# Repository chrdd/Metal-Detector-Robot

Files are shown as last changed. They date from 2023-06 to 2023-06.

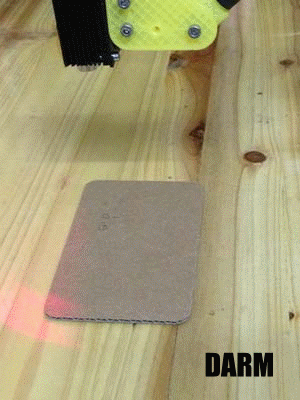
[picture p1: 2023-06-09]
Resources/1204552_3d_print_desktop_robot_arm_DARM_/images/.gif

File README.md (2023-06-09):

# Metal-Detector-Robot
## Introduction
This personal project is aimed at enhancing my knowledge of robotics and Arduinos.

The project initially involved creating a prototype of a metal detector robot with increased degrees of freedom, enabling it to reach greater distances. 


Considering the rising costs of metalworking, I also wanted to develop a cost-effective solution, which led me to research 3D printed arms. I aimed to combine elements from two existing designs:

With metal working being more and more expensive, I also wanted to make something that could be cheap to produce, so I began to do reasearch on 3D printed arms.

I wanted to find a mix between these 2 designs:




Additionally, I aimed to automate the robot as the previous designs relied on manual control through a remote.

## Achitecture
The robot consists of a 4WD project kit car comprising an L298N motor driver and four DC motors, an Arduino Uno, a Raspberry Pi 3A, two NEMA OKY7414 stepper motors, an MG996 servo, a metal detector kit, two stepper drivers, a CNC V3 hat for the Arduino, batteries, and wiring. To complete the arm assembly, I 3D printed a robot arm from Thingiverse ([RobotArm by ftobler - Thingiverse](https://www.thingiverse.com/thing:1718984)), originally intended for an Arduino Mega. The arm required bearings and screws for proper functionality.

### Electrical connections

## Software
The entire project revolves around GRBL, a lightweight G Code interpreter developed in C. This setup allows the Raspberry Pi to calculate the required movements and the Arduino to execute them through the CNC hat, enabling more complex control of the arm.

While GRBL officially supports only stepper motors, there is a modified version called [**grbl-servo**](https://github.com/cprezzi/grbl-servo) that also supports servo control.

G-Code is transmitted from the Raspberry Pi to the Arduino using a serial connection. Additionally, the metal detector sends a high pulse to the Raspberry Pi through pin 36. Furthermore, alongside controlling the arm, the Raspberry Pi manages the DC motors, enabling the car to move.

## Final assembly



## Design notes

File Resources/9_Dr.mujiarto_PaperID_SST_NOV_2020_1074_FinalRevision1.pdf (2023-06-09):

See discussions, stats, and author profiles for this publication at: https://www.researchgate.net/publication/355840656
Design of Arduino-Based Metal Detector Robot (https://www.researchgate.net/publication/355840656_Design_of_Arduino-Based_Metal_Detector_Robot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)

Article in Solid State Technology · November 2021

CITATION
1

READS
8,339

### 3 authors, including:

Some of the authors of this publication are also working on these related projects:

Modelling using artificial intelligence, View project (https://www.researchgate.net/project/Modelling-using-artificial-intelligence?el=1_x_9&_esc=publicationCoverPdf)

UMTAS GRANT View project (https://www.researchgate.net/project/UMTAS-GRANT?el=1_x_9&_esc=publicationCoverPdf)

Mujiarto Bin Parsusah (https://www.researchgate.net/profile/Mujiarto-Bin-Parsusah-2?el=1_x_5&_esc=publicationCoverPdf)
Universitas Muhammadiyah Tasikmalaya

### 48 PUBLICATIONS 156 CITATIONS

SEE PROFILE (https://www.researchgate.net/profile/Mujiarto-Bin-Parsusah-2?el=1_x_7&_esc=publicationCoverPdf)

Aceng Sambas (https://www.researchgate.net/profile/Aceng-Sambas?el=1_x_5&_esc=publicationCoverPdf)
Universitas Muhammadiyah Tasikmalaya

162 PUBLICATIONS 1,610 CITATIONS

SEE PROFILE (https://www.researchgate.net/profile/Aceng-Sambas?el=1_x_7&_esc=publicationCoverPdf)

All content following this page was uploaded by Mujiarto Bin Parsusah (https://www.researchgate.net/profile/Mujiarto-Bin-Parsusah-2?el=1_x_10&_esc=publicationCoverPdf) on 21 July 2022.

The user has requested enhancement of the downloaded file.

Solid State Technology
Volume: 63 Issue: 6
Publication Year: 2020

12401

Archives Available @ www.solidstatetechnology.us

# Design of Arduino-Based Metal Detector Robot

Mujiarto¹

, Aceng Sambas¹

, Irpan Haerudin ¹
1Department of Mechanical Engineering, Universitas Muhammadiyah Tasikmalaya, Indonesia

Corresponding Email: mujiarto@umtas.ac.id

Abstract- Metal Detector Robot is an instrument controlled by an Android-based smartphone that detects the presence of metal, especially landmines, on a designated location. The usage of landmines causing injury and fatality makes detectors important. The old method of detecting landmines such as direct sweeping is very risky for stepping the landmine unintentionally. In this research, the robot system is equipped with a metal detector useful to detect the metal presence based on coil induction when it's approaching the metal. LCD works as an interface showing frequencies of detected metals. The robot movement is controlled by DC's current motor programmed using Arduino UNO. When the robot detects the metal presence, the buzzer sound will be triggered, and the LCD will show the detected metal frequency. The testing result shows that an Android-based smartphone can control the robot up to 15 meters radius. The detection radius is effective up to 88 millimeters from the detector head.

Keywords- arduino uno, metal detector, design, robot

I. INTRODUCTION

We know a variety of materials including metal and non-metal materials. Non-metal materials that we know include wood, plastic, and other materials that are often used in everyday life. In general, metals are divided into ferrous metals and non-ferrous metals [1]. In everyday life, metal materials are usually used to conduct electricity, cooking utensils, jewelry, even for military purposes, one of which is the material for defense equipment such as mines. What we know in the military world, mines are usually planted below the surface of the ground, so that if they are pressed heavily, a mass trampled object will explode. Mines contain explosives that have certain physical and chemical properties [2], [3].

The existence of mines buried in the ground is difficult to know without the aid of tools. One of the tools used to detect the presence of mines is a metal detector [4]. Metal detectors contain a coil of wire known as a transmitter coil. When electricity flows through the coil, a magnetic field is created around the coil. When metal detectors are moved above the ground, the magnetic field will also move. When held close to a metal object, the magnetic field will affect the atoms inside the metal, even changing the way electrons move. The weakness of this metal detector is the high risk of victimization to users because its use still relies on direct human intervention.

Ease of doing a job is now a human need in carrying out its activities so that humans develop a breakthrough in utilizing technology. Utilization of technology to save time and costs. One solution to meet these needs is to use robotics technology that will help even replace some aspects of human work [5].

The use of robots as a tool, of course, is made as closely as possible with what humans do. Some robots are designed to have arms [4], robots that can follow certain colors [5] - [7], robots that can deliver food [8], robots that can guide parking [9], and of course those that are currently developing in connection with the outbreak. Covid-19 is a robot that can shop for daily necessities without the owner having to come to a supermarket or shop [10].

Smartphones communicate with the robot using a radio network (wireless) with the protocol Bluetooth. The data is sent by a cellphone via Bluetooth and received by the robot via adapter Bluetooth. The received data is modulated into serial data with ASCII format. The ASCII code is verified by the program to determine which commands to run. Metal detectors work based on the induction of metal objects in the

12402

enamel coil. The electric induction caused by the coil will change between the presence of metal and no metal. Based on these changes, the metal presence or not can be detected [7].

Metal detection robots are tools to detect the presence of metal or materials containing metal, this robot will notify the presence of metal around the robot by using light or sound [8], [9].

Research on metal detection robots has been carried out by several researchers to produce a metal detection robot design as desired [11] - [13]. Metal detection robot studies were developed based on a microcontroller, to make programming easier. Among them is a metal detection robot based on a microcontroller [11]. Several recent studies in robot design are based on Arduino [9], [14], [15], or some research based on Android [16]. The results of his research describe the application of using an inductive proximity sensor in a metal detector robot based on a 328 microcontroller. The way this robot works is controlled by a wireless remote radio frequency of 315 Mhz, previously a metal detector robot has installed a receiver with a signal that comes out of the wireless remote [12]. The previous metal detector robot was also entitled metal detector for the PLC-based food industry in 2011 [13]. Currently, PLC-based control is still widely used in industries whose equipment uses large power equipment, including in the food industry. The addition of a metal sensor will make it easier to detect food if it is accidentally mixed into food [17].

The purpose of this research is to design an android-based metal detection robot, which can be controlled by a smartphone connected to Bluetooth, with the reliability of being able to detect both ground and underground metals.

II. METHODS

A. Schematic of metal detection robot

This process describes the robot scheme to be built. This scheme is made to simplify the design process because the grooves or cable connections have been validated using the proteus software.

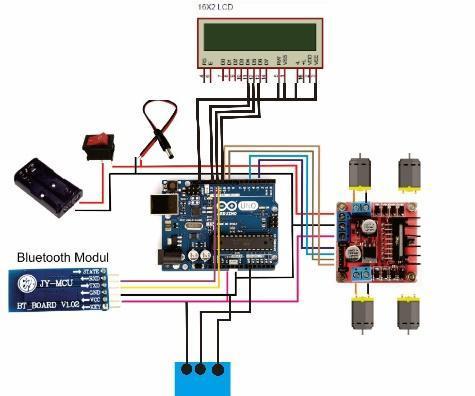
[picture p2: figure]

Figure 1. Scheme of metal detection robot

B. Robot Design
1) Frame

The robot is designed using 2 frames, both of which are made of acrylic material with dimensions of 250 mm x 140mm x 3mm, as shown in Figure 2.

12403

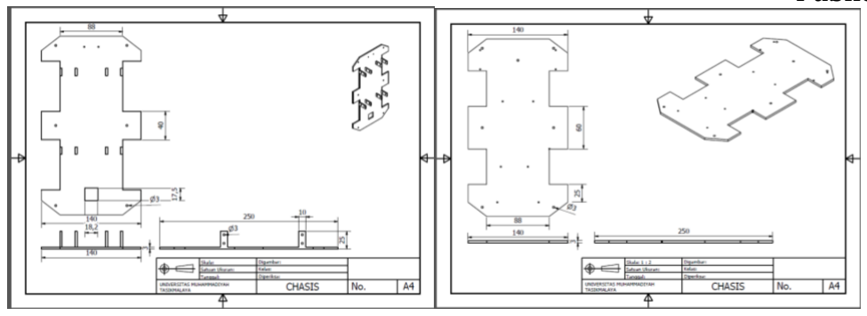
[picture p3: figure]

Figure 2. Frame

2) Gearbox (DC motor)

The drive used for this robot is to use a DC motor [14]. The use of a gearbox is needed to make efficient space on the chassis and change the shaft position of the DC motor because by using a gearbox, a dc motor that should be placed horizontally to distribute its rotation to the wheels can be positioned vertically with a fixed axle.

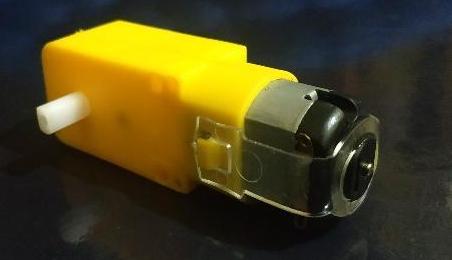
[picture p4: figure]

Figure 3. Gearbox (DC motor)

3) Metal sensor

This component is the most important part in the design of a metal sensor robot, with this component where the detected metal can be detected. For this study, researchers used metal sensors with the following specifications [7]. (a) Detection distance: 0-8mm; (b) Object of detection: Metal (Iron, Aluminum etc.); (c) Working voltage: 10-30V DC; (d)current Output: 300mA; (e) There are indicators: Yes (Red); (f) Working temperature: -25 to +70 C; (g) Size: 18x18x36 mm; (h) Cable length: 1.5m; (i) 34mm x 18.2mm x 17.5mm.

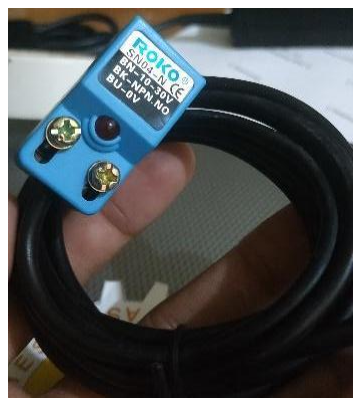
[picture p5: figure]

Figure 4. Metal sensor

4) Buzzer

This component is a component that converts electricity into sound. The buzzer will output the metal sensor robot. This tool will notify by emitting a sound when the metal sensor detects the presence of metal.

12404

Figure 5. Buzzer

5) Battery

This component is the power supply in metal detection robots. The battery used is a battery with a current of 9V, this battery is considered sufficient to supply all the electrical needs of the metal sensor robot, from starting to turn on 4 DC motors, motor drivers, Arduino, metal sensors, buzzer, and LCD dot matrix.

Figure 6. Battery

6) Arduino

Arduino is a board microcontroller, this tool will fully control the robot system from input and output according to what is ordered or programmed on the computer.

7) Motor driver

The motor driver is used to control the direction of rotation and speed of the DC motor [18] - [20], which is the main driving force of the robot. This motor driver will be controlled using a microcontroller by digital input data [7].

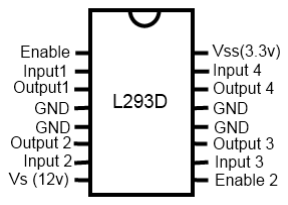
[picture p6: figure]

Figure 7. L239D pin configuration

8) LCD dot matrix

Character numbers, letters, and symbol characters can be displayed on this device, with small current consumption.

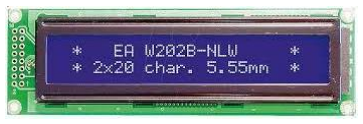
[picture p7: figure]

Figure 8. LCD Dot Matrix

12405

C. Software Design

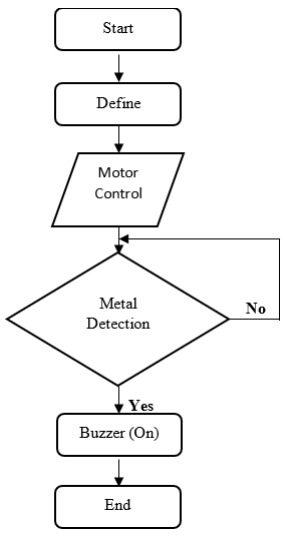
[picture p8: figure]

Figure 9. Flowchart of software design

D. Testing Stages of detector metal with metal variations and distances

Metal detector testing plans are shown in Table 1.

TABLE 1. Testing of metal detector

Metal Type | Distance (cm) | Buzzer
On | Off
Aluminium | 0,5
| 1
| 1,5
Iron | 0,5
| 1
| 1,5
Copper | 0,5
| 1
| 1,5
E. Robot reliability testing

In This testing phase we will measure the strength of the robot in climbing a slope of 30⁰ .

12406

TABLE 2. Robot reliability testing on an incline

Number | PWM | Result | Information
1 | 255
2 | 240
3 | 200
4 | 180
5 | 160

III. RESULTS AND DISCUSSION

A. Results of the Tool Design
1) Software

In the form of programs, the Arduino software program was used as the controller of all components of the robotic device. Arduino UNO is programmed using Arduino software as shown in Figure 10.

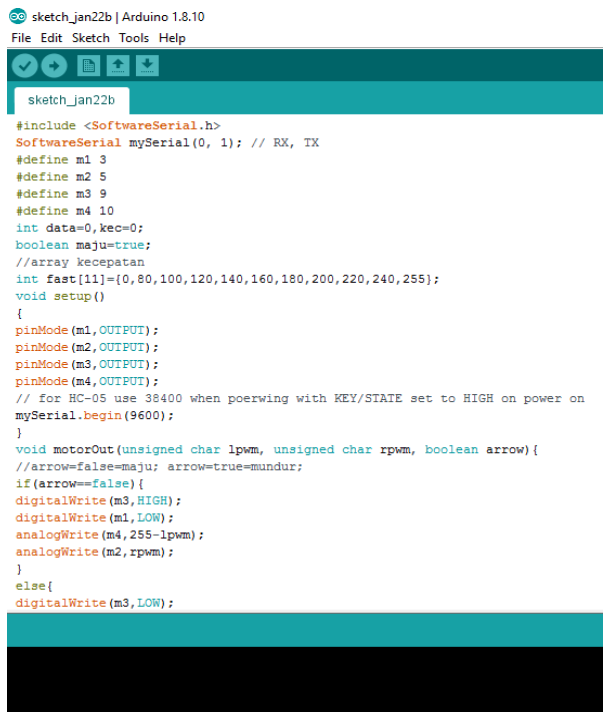
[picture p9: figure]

Figure 10. Program listing

B. Hardware
1) Design Frame

The mainframe of the robot is acrylic. The choice of acrylic material as the chassis is because it is strong, cheap, and easy to form with a size of 140 mm x 250 mm x 3 mm. The robot frame is divided into 2 parts, namely the lower part of the frame which is the support for 4 DC motors, metal sensors, a battery, and support for the upper frame. The upper part is a holder for Arduino, motor driver, buzzer, LCD, which can be seen in Figure 11.

12407

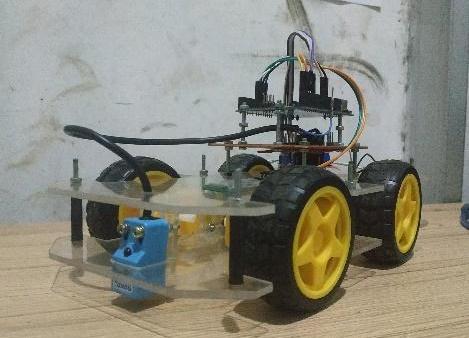
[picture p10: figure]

Figure 11. Results of design

2) The DC circuit

Robot use 4 dc motors as the main drive, this DC motor circuit (Figure 20) is connected to the L298N motor driver which functions to determine the direction of rotation of a dc motor.

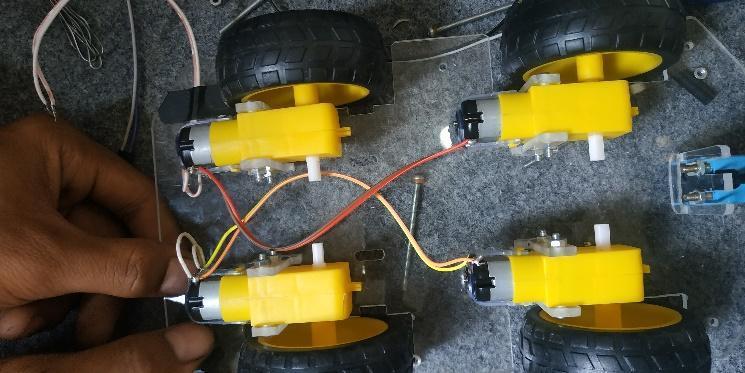
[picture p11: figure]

Figure 12. DC Motor Circuit

3) Robot control using smartphone android

The robot control circuit Bluetooth using smartphone android consists of a smartphone module Bluetooth, circuit Arduino UNO, motor driver L298N, and a DC motor. For more details, see Figure 13.

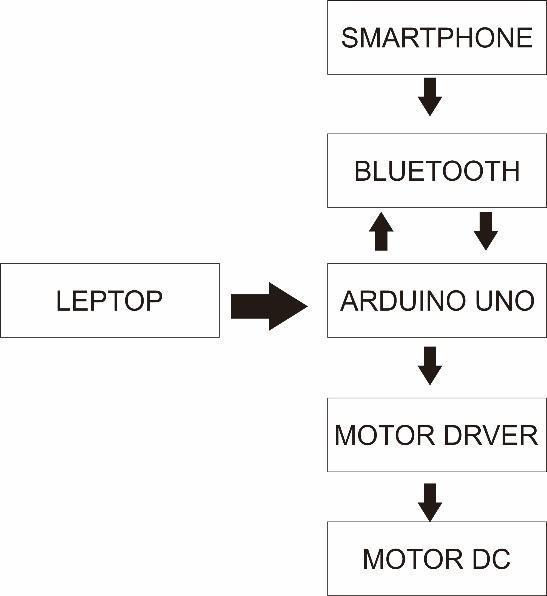
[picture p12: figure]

Figure 13. Robot control circuit

12408

To get a robot control circuit Bluetooth with a smartphone, there is a need for a connection between the module Bluetooth and Arduino using cable a male-female jumper. What must be connected can be seen in Figure 14.

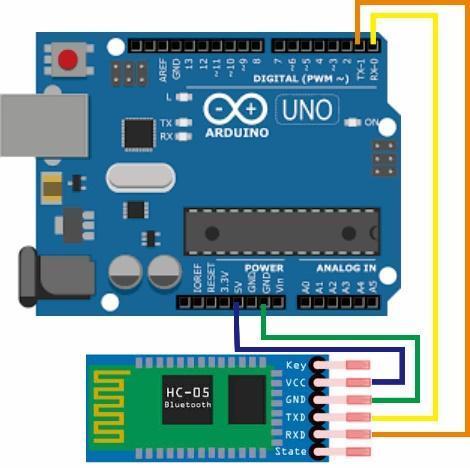
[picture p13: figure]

Figure 14. Bluetooth wiring on Arduino UNO

The principle of controlling a robot requires a smartphone android to control the direction of motion using an application system. Inside it has been given logic data that is sent via Bluetooth HC-05 and entered into the microcontroller system, namely Arduino UNO. Arduino works based on commands that have been programmed and provides data to the motor driver, then the DC motor will determine the direction of rotation.

The results of the analysis of robot control Bluetooth with a Smartphone Android-based on Arduino Uno, this robot uses the Arduino Uno as a robot control system Bluetooth Hc-05, where the command sent by the smartphone to be able to move the Dc motor so that it can move the Arduino-based robot that is made. The Arduino controller RC car is in Figure 15 show, and the Arduino-based metal detector robot designed as shown in Figure 16.

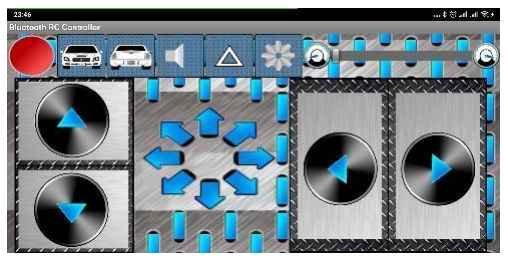
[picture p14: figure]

Figure 15. Arduino controller RC car

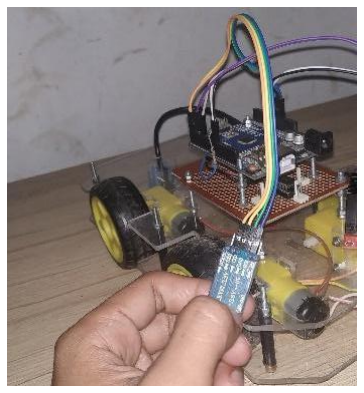
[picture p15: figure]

Figure 16. The result of an Arduino-based robot design

12409

C. The Results of Testing Tool
1) Test results of metal detector

Testing the system input on the sensor connected to the microcontroller with output buzzer and LCD. The use of the buzzer is intended to determine the presence of detected metal, and the use of LCD as a display of the resulting voltage on each detected metal. The results of metal detector testing by placing metal above and below the ground areas in Table 3 and Table 4.

TABLE 3. Metal detector test results (metal placed on the ground)

Metal Type | Distancae (cm) | Buzzer
On | Off
Aluminium | 0,5 | ✔
| 1 | ✔
| 1,5 | | ✔
Iron | 0,5 | ✔
| 1 | ✔
| 1,5 | | ✔
Copper | 0,5 | ✔
| 1 | ✔
| 1,5 | | ✔

TABLE 4. Metal detector test results (metal placed on the ground)

Metal Type | Distance (cm) | Buzzer
On | Off
Aluminium | 0,5 | ✔
| 1 | ✔
| 1,5 | | ✔
Iron | 0,5 | ✔
| 1 | ✔
| 1,5 | | ✔
Copper | 0,5 | ✔
| 1 | ✔
| 1,5 | | ✔
2) Test Results of Robot design

In this stage, testing the robot control. The robot runs when it is on a level place, without obstacles or obstacles, and on the ground with obstacles or without obstacles. This robot uses a DC motor as a driving wheel. This motor has a specification V supply 6V, 1100 rpm, current 1 A.

12410

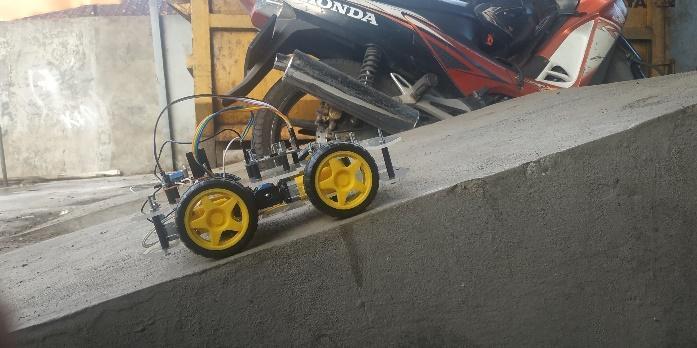
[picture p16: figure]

Figure 17. Reliability testing

This robot is given an incline to find out how strong the robot can climb. In Figure 17, the robot climbs on a flat plane of about 30 degrees with a PWM 160-255. In this condition, the robot can rise. Table 6 below is the provision of PWM values for DC motors to determine which robot PWM values can pass a 30-degree incline.

TABLE 5. Results of testing the robot's strength at a slope of 30⁰.

Slope | PWM | Result
30⁰ | 100 | Not Moving

From the test results, it is known that the PWM value of 100 robots cannot increase. When testing the voltage of battery 7.4 V, the robot can climb on this slope.

IV. CONCLUSION

Metal detectors can detect the presence of metal with a variety of metal types, aluminum, low carbon steel, and copper with a maximum detection distance of 1 cm. The reliability of the robot can move with a terrain slope of 30⁰
, using a 7.4V DC motor, 160-255 rpm rotation.

REFERENCES

[1] M. Maj and K. Pietrzak, “Characteristics of non-ferrous metal alloys as determined by low-cycle fatigue test under variable loads,” Arch. Foundry Eng., vol. 14, no. 1, pp. 71–74, 2014, doi: 10.2478/afe-2014-0017.
[2] B. T. Fedoroff and O. E. Sheffield, “ENCYCLOPEDIA OF EXPLOSIVES AND RELATED ITEMS,”
ENCYCLOPEDIA | OF | EXPLOSIVES | AND | RELATED | ITEMS. | 1969, | [Online]. | Available:
https://www.ncjrs.gov/App/Publications/abstract.aspx?ID=45094.
[3] F. Zapata and C. García-Ruiz, “Chemical Classification of Explosives,” Crit. Rev. Anal. Chem., 2020.
[4] M. A. S. Arifin, “Rancang Bangun Prototype Robot Lengan Menggunakan Flex Sensor Dan Accelerometer Sensor Pada Lab Mikrokontroler Stmik Musirawas,” Ilk. J. Ilm., vol. 9, no. 3, pp. 255–261, 2017, doi: 10.33096/ilkom.v9i3.152.255-261.
[5] R. Mardiyanto, A. Suhartono, and R. F. Siregar, “Development of path planning of line follower robot with obstacles avoidance based on particle swarm optimization,” IOP Conf. Ser. Mater. Sci. Eng., vol. 732, no. 1, 2020, doi: 10.1088/1757-899X/732/1/012098.
[6] A. Sanjaya, H. Mawengkang, S. Efendi, and M. Zarlis, “Stability of Line Follower Robots with Fuzzy Logic and Kalman Filter Methods,” J. Phys. Conf. Ser., vol. 1361, no. 1, 2019, doi: 10.1088/1742-6596/1361/1/012016.
[7] G. Wen, R. Su, K. Yao, F. Zuo, X. Wu, and C. Hui, “Static characteristic analysis of a transmission line detection robot,” IOP Conf. Ser. Mater. Sci. Eng., vol. 740, no. 1, 2020, doi: 10.1088/1757-899X/740/1/012105.
[8] D. A. N. Janis, D. Pang, J. O. W. St, and J. T. Elektro-ft, “Rancang Bangun Robot Pengantar Makanan Line follower,” E-Journal Tek. Elektro Dan Komput., vol. 3, no. 1, pp. 1–10, 2014.
[9] K. Pindrayana, R. Indra Borman, B. Prasetyo, and S. Samsugi, “Prototipe Pemandu Parkir Mobil Dengan Output Suara Manusia Mengunakan Mikrokontroler Arduino Uno,” CIRCUIT J. Ilm. Pendidik. Tek. Elektro, vol. 2, no. 2, pp. 71–82, 2018, doi: 10.22373/crc.v2i2.3705.
[10] W. Ying et al., “Research on Intelligent Shopping Robot Based on PLC,” IOP Conf. Ser. Mater. Sci. Eng., vol. 631, no. 5,

12411

2019, doi: 10.1088/1757-899X/631/5/052033.
[11] Siregar and Y. Artasari, “RANCANG BANGUN ROBOT PENDETEKSI RANJAU DARAT MENGGUNAKAN SENSOR LOGAM BERBASIS MIKROKONTROLER ATMega 8535 SKRIPSI,” UNIVERSITAS SUMATERA UTARA, 2017.
[12] K. T. J. Siswadi, “Design and Realization of Metal Detector Robot,” Institut Teknologi Sepuluh Nopember, 2017.
[13] B. Adebo, A. Abiodun, and O. Adeniji, “Design of an Indoor Metal Detector Robot using Radio Frequency Technology Available online www.jsaer.com Journal of Scientific and Engineering Research , 2019 , 6 ( 1 ): 1-8 Design of an Indoor Metal Detector Robot using Radio Frequency Technology ( RFT ),” no. February, pp. 0–8, 2019.
[14] P. E. Kresnha, D. T. Atmaja, F. F. I. Darda, and R. Alfian, “Perancangan Alat Sensor Parkir Perintah Suara Menggunakan MP3 Shield Arduino,” J. Sist. Informasi, Teknol. Inform. dan Komput., vol. 9, no. September, pp. 49–54, 2018.
[15] P. HANDOKO, “Sistem Kendali Perangkat Elektronika Monolitik Berbasis Arduino Uno R3,” Semin. Nas. Sains dan Teknol. 2017, no. November, pp. 1–2, 2017, [Online]. Available: file:///C:/Users/ASUS/Downloads/2065-4492-1-PB (1).pdf.
[16] A. Zainuri, U. Wibawa, and E. Maulana, “Implementasi Bluetooth HC – 05 untuk Memperbarui Informasi Pada Perangkat Running Text Berbasis Android,” EECCIS, vol. 9, no. 2, pp. 164–165, 2015.
[17] Atmiasari and S. Rochman, “Pendeteksi Logam Untuk Industri Makanan Berbasis Plc,” J. Tek. WAKTU, vol. 09, no. 01, pp. 78–81, 2011.
[18] S. Aryza, Z. Lubis, P. L. Eh Kan, W. Khairunizam, and Hamdani, “Enhanced of Speed Monitoring Brushless DC (BLDC) Equipment and Controller Based on Arduino,” J. Phys. Conf. Ser., vol. 1361, no. 1, 2019, doi: 10.1088/1742-6596/1361/1/012049.
[19] O. V. Kukovinets, K. M. Sidorov, and V. E. Yutt, “Isolated step-down DC -DC converter for electric vehicles,” IOP Conf. Ser. Mater. Sci. Eng., vol. 315, no. 1, 2018, doi: 10.1088/1757-899X/315/1/012015.
[20] X. Zhao, “DC Motor Speed Control System Based on PI Controller,” IOP Conf. Ser. Mater. Sci. Eng., vol. 677, no. 5, 2019, doi: 10.1088/1757-899X/677/5/052007.

View publication stats (https://www.researchgate.net/publication/355840656)

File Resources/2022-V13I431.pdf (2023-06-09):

## Vol 13,Issue 04, APRIL /2022 ISSN NO:0377-9254

www.jespublication.com | PageNo:233

# REMOTE METAL DETECTING ROBOT

Somula Anusha 1, Dr .M. J C Prasad 2

1. Post Graduate scholor, Malla Reddy Engineering College, Kompally, Ranga Reddy, Telangana.
2. Professor, Department of Electronics and Communication Engineering, Malla Reddy Engineering College, Hyderabad-500100, India

Abstract— To develop a robotic vehicle that can sense metals ahead of it on its path similar to sensing land mines. Metal detector robot using Arduino uno this robot is designed for metal detection in places where human being can’t reach easily. Metal detector robot detects metal through metal detector sensor. It detects metals coming to it ways. Wherever it goes, it keeps detecting metal. In case of metal detection, a sound will be produced at the control room or receiver side. This research will give you brief idea about how metal detector robot works.

Keywords— robotic vehicle, metal detection, arduino uno, sensor.

I. INTRODUCTION

Metal detectors are fascination machine; this research is to develop a robotic vehicle that can sense metals ahead of it on its path similar to sensing land mines. It consists of a proximity sensor that detects the metals ahead of it and image in front of the surrounding is sent to the mail. Arduino uno is used for the desired operation. A proximity sensor is mounted on the robot body and its operation is carried out automatically on sensing any metal underneath. As soon as the robot senses this metal it sends the alert. This alerts the operator of a possible metal ahead on its path. A metal detector is a device which responds to metal that may not be readily apparent. The simplest form of a metal detector is the proximity sensor which detects the metal when it is close to some target and it sends the control signal. A highly sensitive proximity sensor and a zigbee is fixed to this robot. When the robot is moving on a surface, proximity sensor detects the metal when the metal is detected the zigbee sends an alert.
The rest of the paper is organized as follows: Section 2 represents the related work, Section 3 represents the background and motivation, In Section 4 we present our approach, In Section 5 we present our simulated results, Section 6 concludes the paper.
II. Related Work
The first industrial metal detectors were developed in the 1960s and were used extensively for mining and other industrial applications [1]. Uses include de-mining (the detection of land mines), the detection of weapons such as knives and guns, especially in airport security, geophysical prospecting, archaeology and treasure hunting. Metal detectors are also used in the construction industry to detect steel reinforcing bars in concrete and pipes and wires buried in walls and floors.
II. Background and Motivation In the present-day scenario, we are facing many threats by bomb blasts. We have existing methods like human surveillance for bomb detection so our research aim is to prepare an unmanned vehicle which detects metal as bombs are usually made of metal.
III. Proposed Approach
In this research we develop a robotic vehicle that can sense metals ahead of it on its path similar to sensing land mines.Arduino Uno is a microcontroller board based on 8-bit ATmega328P microcontroller. Along with ATmega328P, it consists other components such as crystal oscillator, serial communication, voltage regulator, etc. to support the microcontroller [2]. Arduino Uno has 14 digital input/output pins (out of which 6 can be used as PWM outputs), 6 analog input pins, a USB connection, A Power barrel jack and a reset button.
Zigbee works under the IEEE 802.15.4/ZigBee stand with 2.4GHz [3]. Interoperability and worldwide usability needed for only two major modes (Tx/Rx or sleep). Low data rate, low cost and ultra-low power consumption.
The L293D is an integrated circuit motor driver that can be used for simultaneous, bidirectional control dc motors. L293D is a dual H-Bridge motor driver. DC motors which can be controlled in both clockwise and counter clockwise direction.

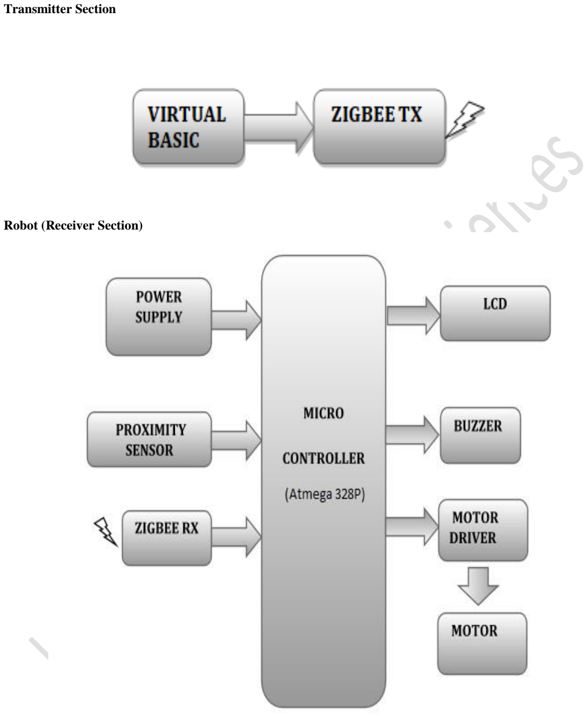
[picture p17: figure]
Transmitter Section; Robot (Receiver Section)

www.jespublication.com | PageNo:234

An inductive proximity sensor is a type of non-contact that is used to detect the position of metal objects. Inductive proximity sensors enable the detection, without contact, of metal objects at distances of up to 60 mm, high operating rates, fast response, excellent resistance to industrial environments, solid state technology: no moving parts, therefore service life of sensor independent of the number of operating cycles. Inductive proximity sensors are solely for the detection of metal objects. They basically comprise an oscillator whose windings constitute the sensing face.

www.jespublication.com | PageNo:235

An alternating magnetic field is generated in front of these windings. When a metal object is placed within the magnetic field generated by the sensor, the resulting currents induced from an additional load and the oscillation causes.

IV. Simulated Result

This project works with the proximity sensor as its metal detector. When the metal is detected, it alerts the operator. The signal alert is also sent to the arduino uno. The arduino uno directly cannot drive the motors. So arduino uno sends the output to the L293 motor driver. This motor driver runs the motors. There are two DC motors. The motors will drive the robot. It consists of a proximity sensor. Whenever the robot finds any metal in its path it stops there and the proximity sensor sends the alert to the control unit. Further the project can be enhanced by live streaming so that the movements of the robot can controlled remotely by watching it on a screen.

www.jespublication.com | PageNo:236

It is most advanced technology. It is of low cost. By using this technology, we can detect the bomb as early as possible and dismantle it easily so that we can easily save the life of the human beings. We can use better sensors and high-end modules to detect meals more precisely.

V. Conclusion
This research presents a metal detecting robot using Arduino uno and zigbee. The mine sensor worked at a constant speed without any problem despite its extension, meeting the specification required for the mine detection sensor. It contributed to the improvement of detection rate, while enhancing the operability as evidenced by completion of all the detection work as scheduled. The tests demonstrated that the robot would not pose any performance problem for installation of the mine detection sensor. On the other hand, however, the tests also clearly indicated areas where improvement, modification, specification change and additional features to the robot are required to serve better for the intended purpose. Valuable data and hints were obtained in connection with such issues as control method with the mine detection robot tilted, merits and drawbacks of mounting the sensor, cost, handling the cable between the robot and support vehicle, maintainability, serviceability and easiness of adjustments. These issues became identified as a result of our engineers conducting both the domestic tests and the overseas tests by themselves, and in this respect the findings were all the more practical.

REFERENCES

[ 1 ] G. Overton and C. Moreland, “History of the Metal Detector”, Inside the Metal Detector. 2016.

[ 2 ] W. P. Osborne, “Download, Install, and test the Integrated Development Environment”, Learn to Program in ArduinoTMC. 2017.

[ 3 ] R. Faludi, “Zigbee and Arduino”, Building Wireless Sensor Networks. edition 1. 2010.

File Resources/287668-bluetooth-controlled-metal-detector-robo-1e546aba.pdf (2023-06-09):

ADBU Journal of Electrical and Electronics Engineering (AJEEE) | Volume 1, Issue 1 | | May 2017

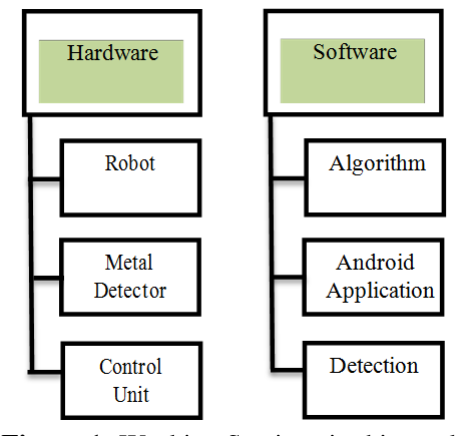
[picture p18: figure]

www.tinyurl.com/ajeee-adbu | | ISSN: 2582-0257 | Page | 1

# Bluetooth Controlled Metal Detector Robot

Ananya Bhattacharyya

Department of Electrical and Electronics Engineering, Assam Don Bosco University, Airport Road, Azara, Guwahati -781017, Assam, INDIA. ananyabhatta@gmail.com

Abstract: This paper presents a new type of robot that uses a metal detector sensor to detect metallic object passing over the metal detector. The robotic vehicle is controlled using android application for metal detection operation controlled with the help of Bluetooth technology. This project can be widely used because of its simplicity and ability to modify to meet changes of needs. Based on experimental studies, it was found that the mobile controlled robot can move in any direction as per the desired instruction and the beeper in the metal detector circuit beeps whenever it encounters any metallic object.

Keywords: Arduino UNO, Bluetooth Module HC-05, Metal Detector, Motor Driver, Android Application

### 1. Introduction

## In today’s modern environment, almost everybody

uses smartphones, which are a part of their day-today life. This project was about robotic movement control through smartphones. Many researchers [1] have developed such robotic movement control system using smartphones. Here, we aim to make a robot and to connect the metal detector circuit to it.

Here, a dedicated application has been created to control robotic hardware, which controls the movement of the robot. The embedded hardware has been developed on ATmega328P microcontroller and controlled by an Android smartphone. This controller receives the commands from the Android phone, takes the data and controls the motors of the robot by the motor driver L293D. The robot can able to move forward, backward, left and right movements. The Smartphone is been interfaced to the device by using Bluetooth. A Bluetooth device HC-05 module was used with Arduino UNO to receive commands from the smartphone. A metal detector circuit was connected to the robot to detect the metal. A beep sound was made when it detected the metal.

### 2. Methodology

This work is divided into two sections- hardware and software. Hardware section contains robot making, metal detector, and control unit. In the hardware section, we explain the working of Arduino and DC motors and how the robot utilizes them to detect the metallic obstacles. In the section of the metal detector, we describe general information about kind of metal detector and working principles. In the section of the control unit, we describe what kind of microcontroller we use. While in the software section, we explain the algorithm that we use in making the android application and metal detector.

A simple block diagram is shown in Figure 1 below.

Figure 1: Working Sections in this work

### 3. Hardware Design

Hardware design consists of the Bluetooth controlled robot and the metal detector circuit. In this work, we utilized the components to build a configurability robot to reach our goal.

The circuit for Bluetooth controlled metal detector robotic car is shown in Figure 2. The Motor driver is connected to Arduino to run the car. Motor driver’s input pins 2,7,10 and 15, are connected to Arduino digital pin numbers 12, 11, 10 and 9 respectively. Here we have used two DC motors to drive a car in which one motor is connected at t h e output pin of motor driver- 3 and 6; and another motor is connected to pins- 11

ADBU Journal of Electrical and Electronics Engineering (AJEEE) | | www.tinyurl.com/ajeee-adbu

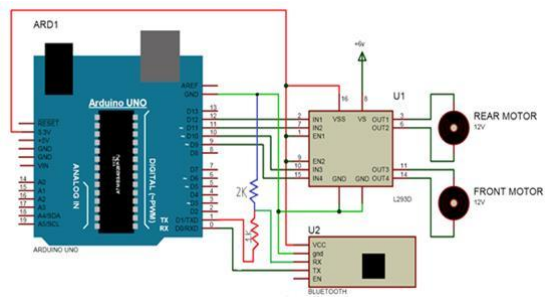
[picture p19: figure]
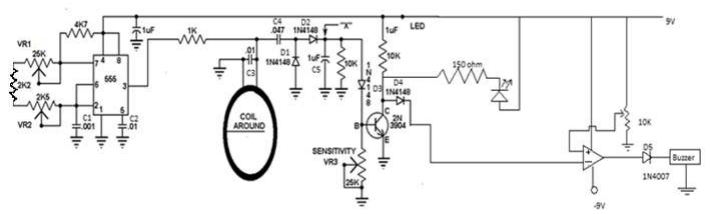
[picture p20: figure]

Bhattacharya, AJEEE, ISSN: 2582-0257, Vol. 1, Issue 1, May 2017, pp. 1-5 | | | Page | 2

and 14. A 9V battery is also used to power the motor driver for driving motors. The Rx pin of the Bluetooth module is connected to a voltage divider. From the voltage divider, one end is connected to the Tx pin of the Arduino and the other end is connected to the ground (GND) pin of the Arduino. Then the Tx pin of the module is connected to the Rx pin of the Arduino.

### 3.1 Robotic vehicle circuit

The robotic vehicle consists of Arduino UNO, Bluetooth Module HC-05, Metal Detector, Motor Driver and two DC Motors. The Vcc and ground pin of Bluetooth module is connected to 3.3V and ground of Arduino. A 9V battery is also used for power the circuit at Arduino Vin pin.

### 3.1 Metal detector

In this work, we mainly depend on a metal detector, because we need to decide the object is metallic or non-metallic. A metal detector device detects the presence of metal nearby. It takes advantage of the electric and magnetic properties of metals (Eddy currents) to detect metals [2].

The circuit for the metal detector circuit is shown in Figure 3, whose working is as follows.

Here the circuit is divided into three parts, an astable multivibrator, an LC circuit, and a comparator circuit. In the first stage i.e., the astable multivibrator circuit (using NE 555 IC), by giving a supply to the circuit it produces a frequency (say f1) and this frequency is fixed by adjusting the variable resistor R1 and R2 which are of the value 2K and 25K respectively. It produces a square wave at the output pin (i.e. pin 3) of the IC and is adjusted to give a frequency of 0.7 MHz.

In the second stage is the LC circuit. The inductance (L) here is a copper coil. When a metal is kept near to the coil, the electromagnetic field in the coil is disturbed which produces a frequency (say f2). The frequencies f1 and f2 meet at a junction. If frequency f1 is greater or lesser then f2, it produces a voltage V, the voltage flows through the diodes. The negative voltage flows through diode D1, which is in reverse bias that is connected to the ground and it gets neutralize here. Whereas, the positive voltage flows through diode D2 which is in forward bias. The capacitor C5 reduces the

Figure 2: Robotic Vehicle Circuit using Arduino UNO

Figure 3: Robotic Vehicle Circuit using Arduino UNO

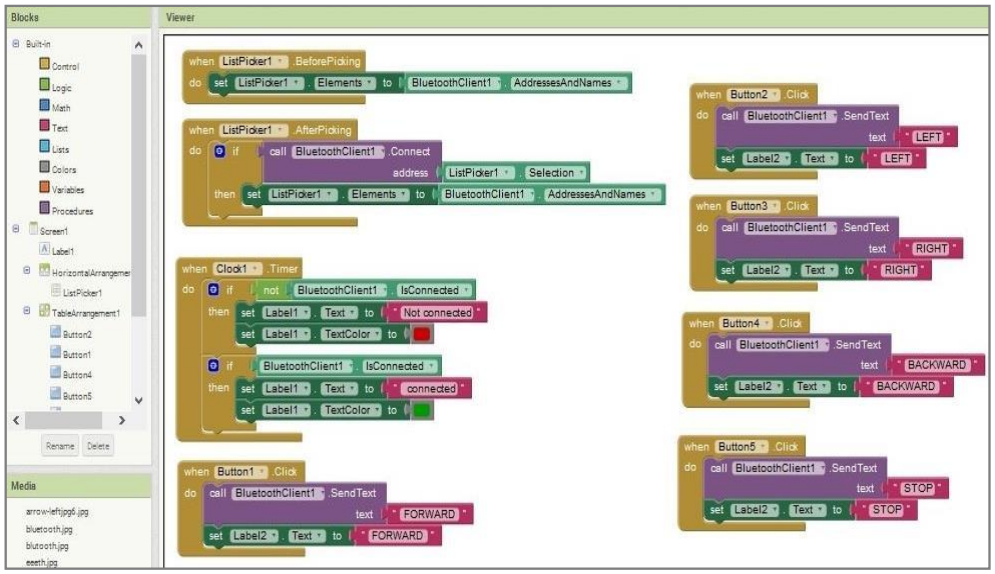
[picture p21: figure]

Bhattacharya, AJEEE, ISSN: 2582-0257, Vol. 1, Issue 1, May 2017, pp. 1-5 | | | Page | 3

ripples in the voltage. Whenever the voltage flows through diode D3, if there is any negative voltage, it will be blocked by the diode and only positive voltage is allowed to pass which then flows to the NPN transistor. The transistor will be switched ON and a positive voltage will flow through diode D4; and then a positive voltage will flow to the pin 2 of the op-amp in the comparator circuit, which is in inverting mode. Here a variable resistor is connected to pin 3 of the op-amp, which sets the reference voltage of the comparator circuit. Here the voltage at pin 2 will be lower than the reference voltage at pin 3, so the output at pin 6 (output pin) will be high and a voltage from the op-amp will flow to diode D5 and then to the buzzer and the buzzer will beep.

However, when there is no metal near the coil, frequency f1 will be equal to f2, the voltage produced at the junction will be zero, and hence there will be no voltage flowing across the circuit. The input at pin 2 will be more than the reference voltage, so the output will be low, therefore the buzzer will not beep.

3.3 | Control | Units | (Arduino | UNO,
ATmega328P Microcontroller)

The Arduino Uno is the main hardware control unit, which is a microcontroller board and is based on the ATmega328P. It has 14 digital input/output pins, 6 analog inputs, a 16 MHz quartz crystal, a USB connection, a power jack, an ICSP header and a reset button [3]. It contains everything that is needed to support the microcontroller; simply it needs to be connected to a computer with a USB cable or power it with an AC-to-DC adapter or battery, to get started.

### 4. Software Design

In this section, algorithms used in making the android application and metal detection, have been briefly explained. Here, we utilized the advantages of an Android smartphone. The software components have been described with more details.

### 4.1 Algorithm

The general algorithm has the main steps to
accomplish the general tasks, which are “start”,

## “stop” and “detection of metal”. The program will begin with the “start” step where the Bluetooth

module HC-05 connected to Arduino Uno will pair with the android application. The robot moves as per the instruction, given by the Android Application. During this step, the robot moves and the metal detector checks if the object is a metallic object or not through passing it over the metal detector. In case, if a metallic object is countered by the metal detector, a beep sound will be produced by the beeper and the movement of the robot can be stopped. Otherwise, the robot will travel until it finds any metallic object, or else the movement robot can be stopped.

### 4.2 Android Application

Android is a very familiar word in today’s world.
Millions of devices are running on Android OS and millions are being developed every day [4]. App Inventor is an application originally provided by Google and now maintained by the Massachusetts Institute of Technology (MIT). It allows anyone to create software applications for the Android Operating System (OS). It uses a graphical interface that allows users to create an application

Figure 4: App Inventor Designer

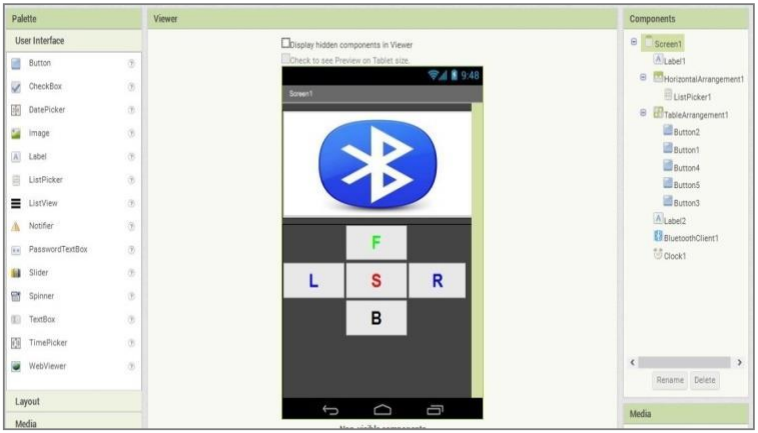
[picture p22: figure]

Bhattacharya, AJEEE, ISSN: 2582-0257, Vol. 1, Issue 1, May 2017, pp. 1-5 | | | Page | 4

that can run on the Android system, which runs on many Android phones [5].

The first phase of application design goes through the App Inventor Designer, which is accessible through the web page. The left side of the window consists of ingredients like a screen, buttons, text boxes, images, labels and many more and the right side of the designer allows users to view the screen and components added to the screen.

In this app development, the App Inventor provides a versatile opportunity to develop a customized application that starts with establishing a Bluetooth connection by searching the available Bluetooth devices and make pair with them. For robotic movement, a character is assigned for each operation such as Forward-“F”,
Backward-“B”, Left-“L” and Right-“R”.

### 4.3 Detection

This task completely depends on the metal detector. Whenever the metal detector comes across and metal, it detects the metal by making a beep sound.

### 5. Operation of the System

The project is designed to control a metal detector robotic vehicle using an android application. Bluetooth device is interfaced to the control unit for sensing the signals that are transmitted by the android application. This data is conveyed to the control unit, which moves the robot. An

ATmega328P microcontroller is used in this project as a control device.

Remote operation is achieved by any smartphone with Android OS, upon a GUI (Graphical User Interface) based touch screen operation. We used the HC-05 module to pair the Android application to the robot. The motors are interfaced to the control unit through motor driver L293D IC. An extra metal detector circuit is connected to the robot to detect the metal efficiently.

### 6. Conclusion and future scope

This project presents a metal detecting robot using Bluetooth communication with Bluetooth module HC-05. The robot is moved in a particular direction with the help of Bluetooth technology, controlled by our mobile. Experimental work has been carried out successfully. The result shows that higher efficiency is achieved using the embedded system. This proposed method is verified to be highly beneficial for many purposes [6]. The metal detector worked at a constant speed without any problem. In this project, we also achieved wireless communication between the robot and the Android application.

This project can be further developed by enhancing the performance and by adding more features. Further developments in this project can be an addition of features like the addition of a gas sensor, connecting robotic arms for pick and place purposes etc.

Figure 5: Apps Inventor Block Editor

Bhattacharya, AJEEE, ISSN: 2582-0257, Vol. 1, Issue 1, May 2017, pp. 1-5 | | | Page | 5

References

[1] A. R. Yeole, S. M. Bramhankar, M. D. Wani

## and M. P. Mahajan, “Smart Phone Controlled

Robot Using ATMEGA328 Microcontroller”,
International Journal of Innovative Research in Computer and Communication Engineering (IJIRCCE), Vol. 3, Issue 1, Jan. 2015, pp. 353-
356. | Retrieved | from
http://www.ijircce.com/upload/2015/january/31_Smart.pdf
[2] H. Alsahafi, M. Almaleky and T. M. Sobh,

## “Design and Implementation of Metallic Waste

Collection Robot”, Presentation at Faculty Research Day, School of Engineering, University of Bridgeport, Bridgeport, 28
March | 2014. | Retrieved | from
https://scholarworks.bridgeport.edu/xmlui/handle/123456789/558

## [3] P. Kumar and P. Kumar, “Arduino Based

Wireless Intrusion Detection Using IR Sensor and GSM”, International Journal of Computer Science and Mobile Computing (IJCSMC), Vol. 2, Issue 5, May 2013, pp. 417-424.
Retrieved | | | | from
https://pdfs.semanticscholar.org/b60e/75e252a 4cdf4e708e73af1e12f869208b6f9.pdf
[4] J. K. Winter, Android Controlled Mobile Robot, Final Year Project Report, Industrial
Engineering, | Department | of | Systems
Engineering and Automation, Universidad Carlos III de Madrid, July 2013, Madrid.
Retrieved | | | | from
http://wiki.asrob.uc3m.es/images/1/1d/PFC_-_Jorge_Kazacos.pdf
[5] M. Selvam, “Smart Phone Based Robotic
Control | for Surveillance Applications”,
International | Journal | of | Research | in
Engineering and Technology (IJRET), Vol. 3, Issue 3, March 2014, pp. 229-232. Retrieved from
https://doi.org/10.15623/ijret.2014.0303043
[6] H. Aoyama, K. Ishikawa, J. Seki, M. Okamura,
S. Ishimura and Y. Satsumi, “Development of

## Mine Detection Robot System”, International

Journal of Advanced Robotic Systems, Vol. 4, Issue 2, June 2007, pp. 229-236. Doi: https://doi.org/10.5772/5693

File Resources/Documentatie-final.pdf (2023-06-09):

# Robot cu detector de metale

Profesor coordinator : Trăsnea Bogdan

Nume : Sandu Octavian

Programul de studii : Automatica

Grupa : 4LF411

An : 2022-2023

## Cuprins

## 1. Introducere

Ideea acestui robot a pornit de la robotii folosiți pentru detectarea minelor, fiind un concept destul de interesant pentru mine.

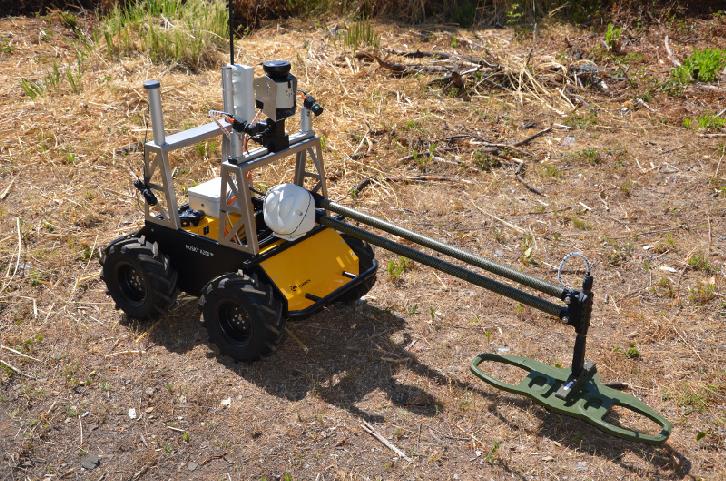
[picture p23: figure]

Am vrut sa construiesc o varianta mai simpla care ar putea fi printata 3d. Astfel, am găsit 2 modele de roboti, eu dorind sa pic undeva intre acestea din punct de vedere al complexității.

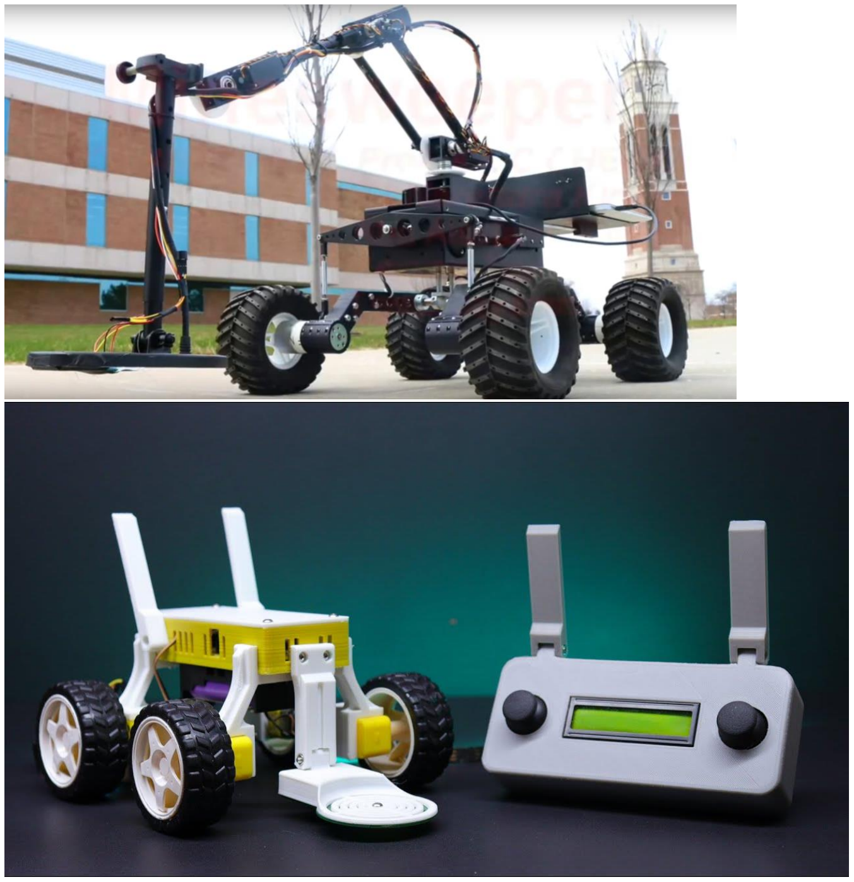
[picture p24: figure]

Mi-am dorit ca acesta sa fie complet autonom, cele doua modele prezentate anterior fiind controlate prin telecomanda.

Ideea inițială a acestui proiect a fost sa controlez totul cu un Raspberry Pi pentru ca știam deja cum sa folosesc sistemul de operare Linux, însă am descoperit destul de repede ca nu era posibil. In final, am ajuns la configurația actuala, aceasta fiind un Raspberry Pi 3A+ si un Arduino Uno cu un CNC Hat V3 conectate prin Serial.

## 2. Arhitectură

Inițial am comandat un Kit Robot 4WD ca si baza pe care sa montez brațul robotic. Acesta a venit cu șasiul, 4 motoare DC de 12V, o punte H l298n si un Arduino Uno.

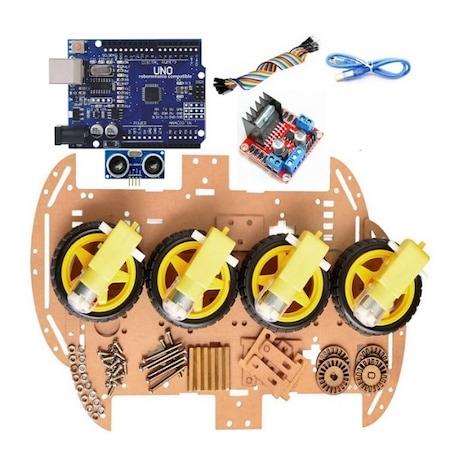
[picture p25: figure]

Pe lângă aceste am mai utilizat următoarele:
- Un kit circuit detector de metale


- 2 Drivere pentru motoare pas cu pas (Stepper)


- O placa de expansiune CNC V3


- Un motor servo MG996


- 2 motoare pas cu pas (stepper) NEMA OKY7414


- Cabluri, baterii de 9V si conectori pentru baterii

Pe lângă acestea, am avut nevoie de un braț pe care sa montez detectorul de metale

printat 3D un braț (https://www.thingiverse.com/thing:1718984) , conceput original in jurul unei placi RAMPS pentru un Arduino Mega (https://www.reprap.org/wiki/RAMPS_1.4).


Bratul a fost printat folosind imprimanta Ender 3 Pro si utilizând PLA+.

Acest model folosește 3 motoare stepper si un servomotor pentru a acționa cleștele, însă pentru mișcarea pe axa Z am decis sa folosesc un servo pentru a păstra greutatea cat mai mica.

Pentru acesta am avut nevoie de:
- 10 rulmenți 686 ZZ SRBF (686-2z)
- 1 rulment 51105 SRBF (51105-srbf)
- 6 rulmenți 624 ZZ SRBF (624-zz-srbf)
- Șuruburi M3 si M4 împreună cu piulițele adecvate

## 3. Conectarea componentelor


Conectarea componentelor este realizata astfel:

## 4. Programarea

Arhitectura acestui proiect este bazata pe GRBL, un software pentru interpretarea codului G-Code. G-Code este cel mai utilizat limbaj pentru platformele de printare 3D si CNC, care ajuta miscarea componentelor in spatiul 3D utilizand axele XYZ.

In mod official, GRBL accepta doar motoare stepper, insa exista o versiune modificata a acestuia ce poate controla si motoare servo, numit grbl-servo. (https://github.com/cprezzi/grbl-servo)

Comenzile in G-Code sunt transmise din Raspberry Pi prin serial catre Arduino pe baza detectorului de metale, acesta transmitand un semnal High cand detecteaza un obiect metalic pe pin-ul 36 (GPIO 16).

Pe langa acesta, programul pentru a controla motoarele este standard, scris in python:

import RPi.GPIO as GPIO
from time import sleep

in1 = 24
in2 = 23
en = 25
temp1=1

GPIO.setmode(GPIO.BCM)
GPIO.setup(in1,GPIO.OUT)
GPIO.setup(in2,GPIO.OUT)
GPIO.setup(en,GPIO.OUT)
GPIO.output(in1,GPIO.LOW)
GPIO.output(in2,GPIO.LOW)
p=GPIO.PWM(en,1000)
p.start(25)
print("\n")
print("The default speed & direction of motor is LOW & Forward.....") print("r-run s-stop f-forward b-backward l-low m-medium h-high e-exit") print("\n")

while(1):

x=input()

if x=='r':
print("run")
if(temp1==1):
GPIO.output(in1,GPIO.HIGH) GPIO.output(in2,GPIO.LOW)
print("forward")
x='z'
else:
GPIO.output(in1,GPIO.LOW)
GPIO.output(in2,GPIO.HIGH) print("backward")
x='z'

elif x=='s':
print("stop")
GPIO.output(in1,GPIO.LOW)
GPIO.output(in2,GPIO.LOW)
x='z'

elif x=='f':
print("forward")
GPIO.output(in1,GPIO.HIGH) GPIO.output(in2,GPIO.LOW)
temp1=1
x='z'

elif x=='b':
print("backward")
GPIO.output(in1,GPIO.LOW)
GPIO.output(in2,GPIO.HIGH) temp1=1
x='z'

elif x=='l':
print("low")
p.ChangeDutyCycle(25)
x='z'

elif x=='m':
print("medium")

p.ChangeDutyCycle(50)
x='z'

elif x=='h':
print("high")
p.ChangeDutyCycle(75)
x='z'

elif x=='e':
GPIO.cleanup()
break

else:
print("<<< wrong data >>>")
print("please enter the defined data to continue.....")

## 5.Ansamblarea finala

Cea mai complexa parte a robotului a fost miscarea pe axa Z. Bratul este situate pe 3 rulmenti prinsi intre un surub si o piulita.


In urmatoarele imagini este prezentat robotul final



## 6. Probleme

- Puntea H nu accepta mai mult de 12V, ceea ce este necesar pentru alimentarea tuturor celor 4 motoare
- Puntea H nu distribuia tensiunea echivalent, astfel decat 2 motoare primeau curent.
- Am incercat multiple programe pentru a controla puntea H, insa nici unul nu functiona corect
- Puntea H a cerut mai mult de 5V din Raspberry Pi, astfel arzandu-l
- Motoarele DC au conectori foarte fragili, s-au rupt de 3 ori pe fiecare motor
- Cablurile din kit sunt foarte fragile
- Arduino-ul nu ruleaza instructiunile din GRBL in mod corect, nu proceseaza mai mult de 4 instructiuni fara a trimite erori, instructiunile pe care le proceseaza sunt inconsistente (aceeasi instructiune produce rezultate diferite)
- Potentiometrul driverelor se invarte in gol (in mod normal au un minim si maxim)

- Am ars un driver deoarece l-am pus invers
- Contactele puntei H si al placii de expansiune pentru sursa de curent nu prind cablurile
- Rulmentii si suruburile au fost foarte greu de gasit, fiind nevoie sa fie comandate de pe internet (in unele cazuri imposibil de gasit)
- Dimensiunile unor modelel 3D sunt gresite ( gaurile pentru rulmenti sunt prea mari sau prea mici )

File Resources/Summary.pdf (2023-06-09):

# Metal Detector Robotic Vehicle


## Submitted by:

Muhammad Naveed Ahsan | 13018019043
Ahmad Hamza | 13018019100
Abdul Qadeer | 13018019086
Muhammad Ameer-ul-Faheem | 13018019169

## In the Supervision of

## Sir Saleem Ata

## Department of Electrical Engineering

## School of Engineering

## University of Management and Technology Lahore

## May 2017

# Metal Detector Robotic Vehicle

## Submitted by:

Muhammad Naveed Ahsan | 13018019043
Ahmad Hamza | 13018019100
Abdul Qadeer | 13018019086
Muhammad Ameer-ul-Faheem | 13018019169

## In the Supervision of

## Sir Saleem Ata

## Department of Electrical Engineering

## School of Engineering

## University of Management and Technology Lahore

## May 2017

## Submitted to the faculty of the Electrical Engineering Department of the University of Management and Technology Lahore in partial fulfillment of the requirements for the Degree of

## Bachelor of Science

In

## Electrical Engineering

____________ | ___________
Project Advisor | Director Undergraduate Studies


# University of Management and Technology

# Acknowledgement

## First of all, we would like to express our gratitude to Allah Almighty who

helped us in every field of our life.

Secondly, we would like to thank our parents for their love and support.

## And finally special thanks to Sir Saleem Ata who approved our idea and helped us a lot in everything. Without his help and support, we would never be able to

do this project. His believe in us, motivates us to complete this project.

# Declaration

### This report is based on our own research and implementation. Any contribution of

any person is indicated in acknowledgements and references.

## This project is supervised by Sir Saleem Ata at University of Management and

Technology.

# Signed: _________

# Signed: _________

# Signed: _________

# Signed: _________

# Date: __________

## TABLE OF CONTENTS

ACKNOWLEDGEMENT | II
DECLARATION OF ORIGINALITY FORM | III
TABLE OF CONTENTS | IV
LIST OF FIGURES | VI
ABSTRACT | VII
CHAPTER 1: INTRODUCTION | 1-4

### 1.1 Background 1.2 Problem Description 1.3 Objectives 1.4 Scope of Work 1.5 High Level Description 1.6 Report Orientation 1.7 Software Basics 1.8 System Necessities

CHAPTER 2: LITERATURE REVIEW | 5

### 2.1 Robotic Vehicle 2.2 Gear Motor 2.3 Servo Motor 2.4 Arduino

CHAPTER 3: HARDWARE DESCRIPTION | 6-18

3.1 Metal Detecting Sensor 3.2 Arduino 3.2.1 Master Slave Combination of Arduino 3.2.2 Advantages of Arduino 3.3 DC Gear Motor 3.4 Nuts, Bolts and Spring Washers 3.5 Motor Driving Module L298n 3.6 Robotic Chassis 3.6.1 Dimensions of Robotic Chassis 3.7 Mechanical Arm 3.7.1 Dimensions of Mechanical Arm 3.8 Servo Motors Bluetooth Module HC-05 3.9 Wireless Camera 3.10 Bluetooth Module 3.10.1 Connecting Smartphone with Bluetooth Module 3.11 DC Battery
CHAPTER 4: USER MANUAL | 19-20

### 4.1 How to start Robotic Vehicle

### 4.2 How a User can tell if the Vehicle is in Working Condition 4.3 Troubleshooting

CHAPTER 5: CONCLUSION & FUTURE RECOMMENDATIONS 21-22

### 5.1 Conclusion 5.2 Future Recommendations 5.2.1 Circuit 5.2.2 Bluetooth Module 5.2.3 Sensor 5.2.4 Wireless Camera 5.2.5 Overall System

REFERENCES | 23
APPENDIX | 24

LIST OF FIGURES

Figure 3.1 | Metal Detector Sensors
Figure 3.2 | Metal Detector Circuit
Figure 3.3 | Datasheet of Arduino UNO
Figure 3.4 | Arduino UNO
Figure 3.5 | Pin Configuration of Arduino UNO
Figure 3.6 | Exterior Assembly of DC Gear Motor
Figure 3.7 | Gears of DC Motor
Figure 3.8 | Nut, Bolt and Washers
Figure 3.9 | Motor Driving Module L298n
Figure 3.10 | Block Diagram of H-Bridge
Figure 3.11 | Chassis of Robotic Vehicle
Figure 3.12 | Back Wheels of Vehicle along with DC Motors
Figure 3.13 | Mechanical Arm
Figure 3.14 | Servo Motor
Figure 3.15 | Internal Structure of Servo Motor
Figure 3.16 | Wireless Camera & Receiver
Figure 3.17 | Pin Configuration of Bluetooth Module
Figure 3.18 | DC Battery
Figure 4.1 | Bluetooth Module not Connected
Figure 4.2 | Bluetooth Module Connected

ABSTRACT

Landmines are the most destructive equipment which are laid under some feet’s or on surface of grounds.

They explode once a living things’ foot make contact with the spring at the top of the mine.

These killing machines are laid in the vast fields and are very difficult to detect by naked eye .These killing

machines needs to be identified and living things should be saved from this slaughtering equipment. This

robot which will go into fields and detect landmines which are under ground by the help of metal detector

sensor which is placed at the front of our robotic vehicle. Robot will be moved with the help of Bluetooth

module which will drive motors. This robotic vehicle would be controlled by an android phone using

Bluetooth RF application.

## CHAPTER 1

## INTRODUCTION

### 1.1 Background:

According to a report by CNN there are thousands of people who are killed by land mines, most of whom

are civilians.Landmines contain explosive matter with eruptive system which burst when a person or

vehicle make contact with it.Landmines are commonly placed 15cm below ground or sometimes on

field.Majority of them are innocent and some lose their loved ones. In many cases, there are even more

dangerous and heartwarming outcomes but the danger remains due to the difficulty of finding and

destroying the mines. So it is very important that these death machines should be detected and removed in

order to save lives of innocent civilians, and with thousands of them planted worldwide it is a challenging

task. It is very compulsory to disarm them. According to ICBL(International Campaign to Ban Landmines)

number of injuries across the globe rose up to 6461 in 2015, which is 75% of preceding year .According to informationcitizens, were more than three quarters and 38% were kids. [1]

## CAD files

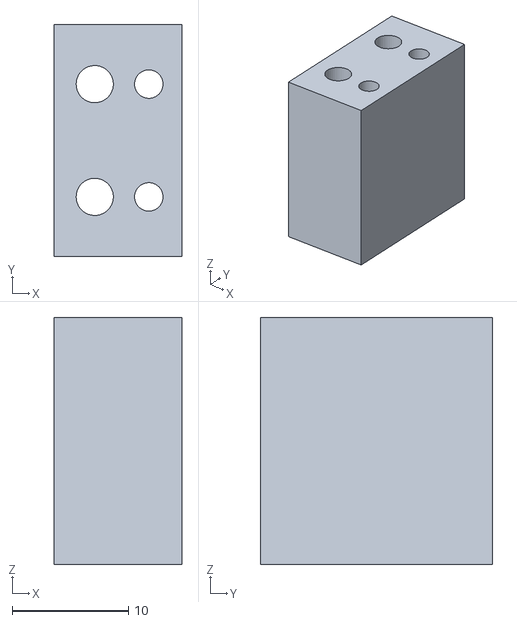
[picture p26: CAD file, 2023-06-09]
Resources/1204552_3d_print_desktop_robot_arm_DARM_/files/mainEndstop.STL
11.0 x 20.0 x 21.2

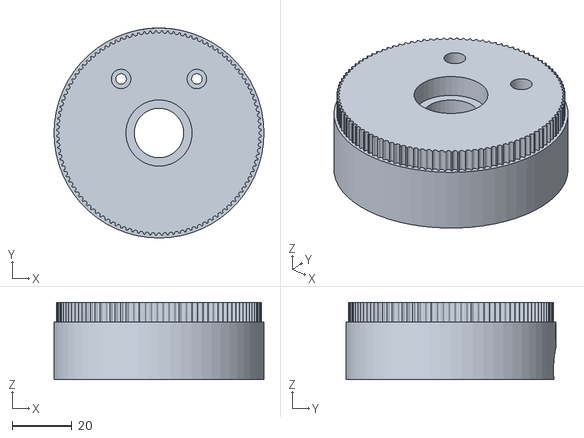
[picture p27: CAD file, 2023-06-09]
Resources/1204552_3d_print_desktop_robot_arm_DARM_/files/mainArmGear.STL
70.0 x 70.0 x 25.7

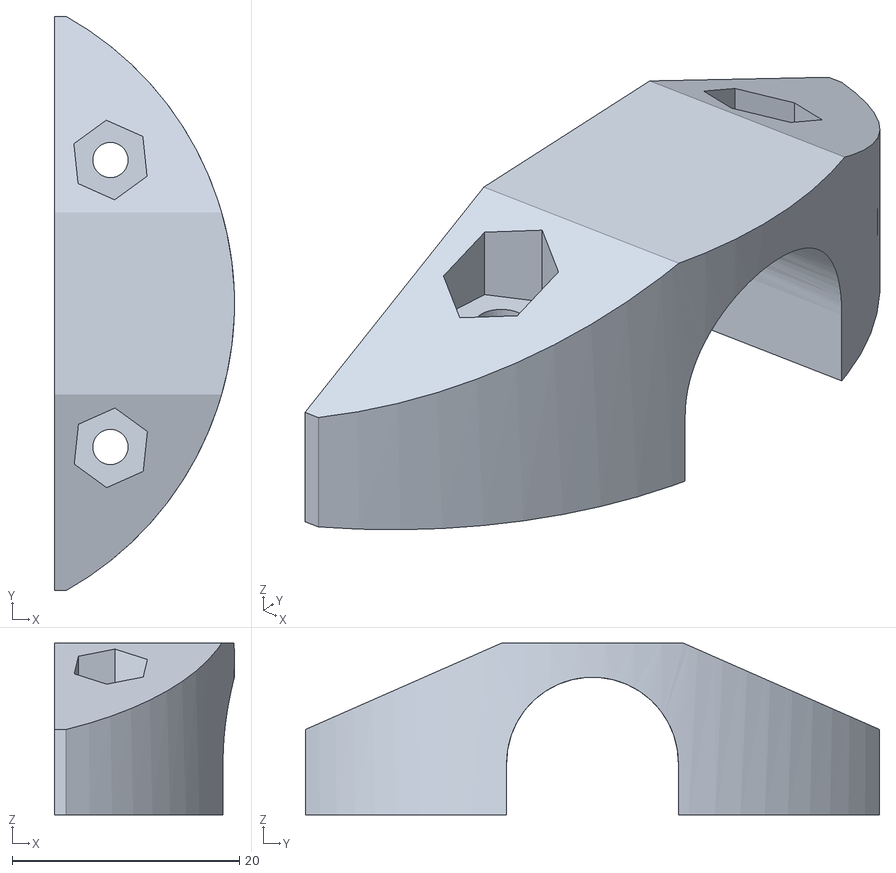
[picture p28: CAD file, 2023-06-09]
Resources/1204552_3d_print_desktop_robot_arm_DARM_/files/mainBracket.STL
15.8 x 50.5 x 15.1

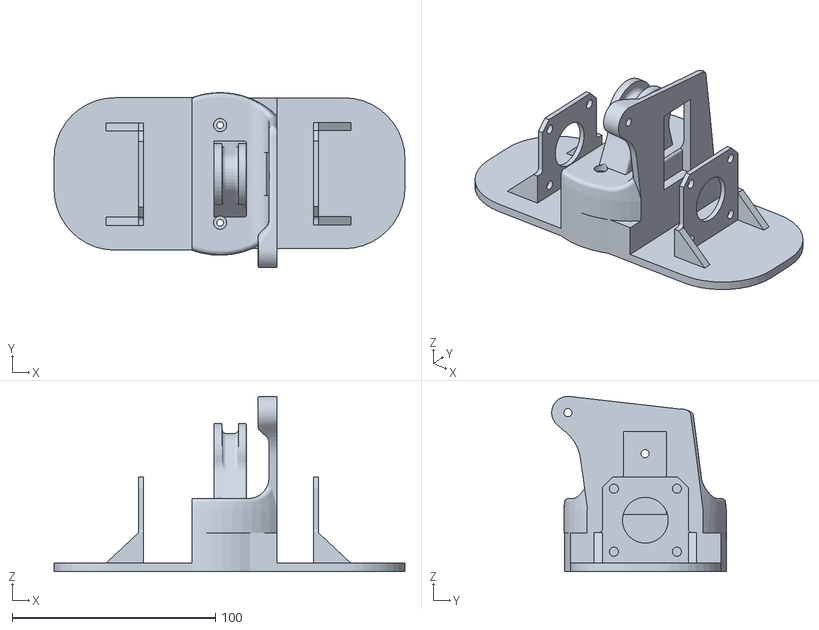
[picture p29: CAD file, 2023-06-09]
Resources/Robot Arm MK2 Plus/Robot_Asm.STL
172.7 x 86.0 x 86.2

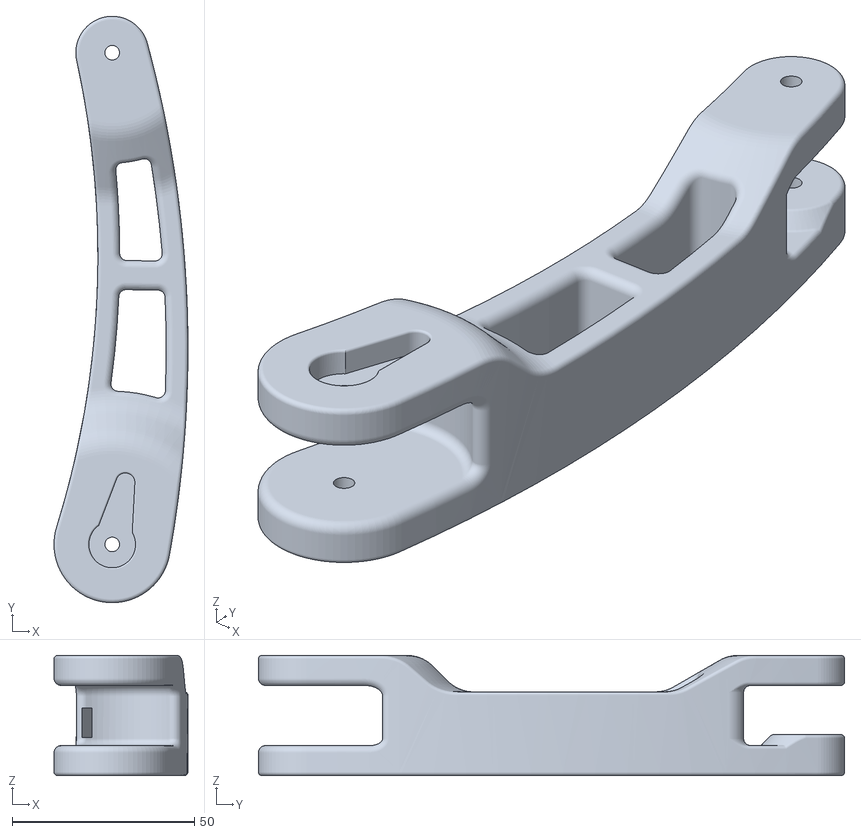
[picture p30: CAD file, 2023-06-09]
Resources/Robot Arm MK2 Plus/EBAmk2_002_mainarm.STL
36.8 x 161.0 x 33.0

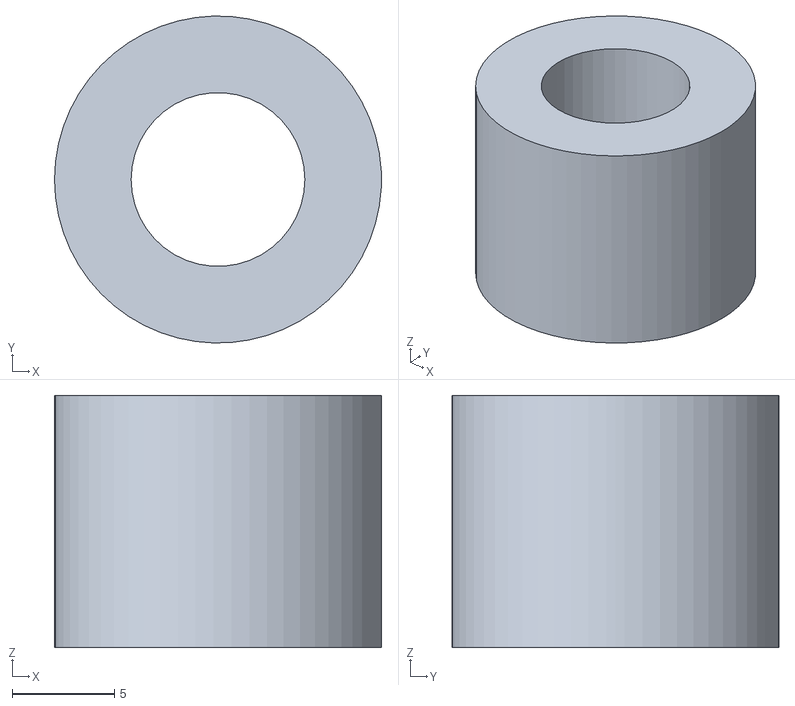
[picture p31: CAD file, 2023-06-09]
Resources/1204552_3d_print_desktop_robot_arm_DARM_/files/1235_MainCennect.STL
16.0 x 16.0 x 12.4

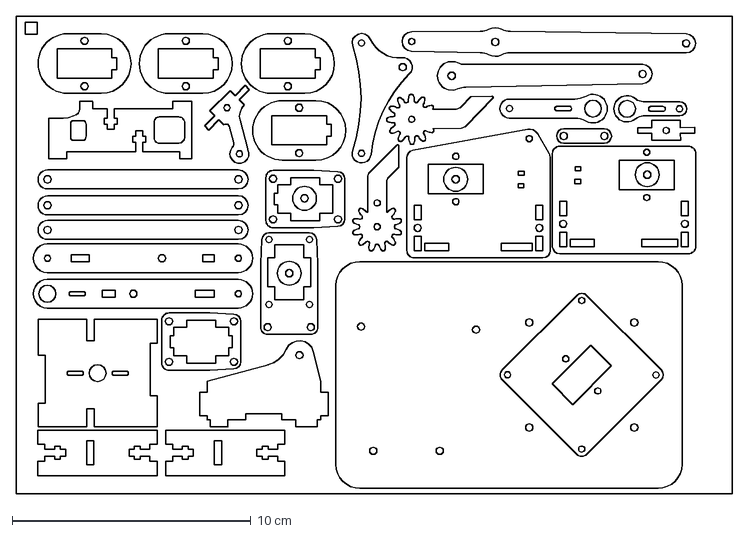
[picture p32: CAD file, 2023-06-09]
Resources/360108_MeArm_V0_4_-_Pocket_Sized_Robot_Arm/files/MeArmV0.4.dxf
30.0 x 20.0 cm

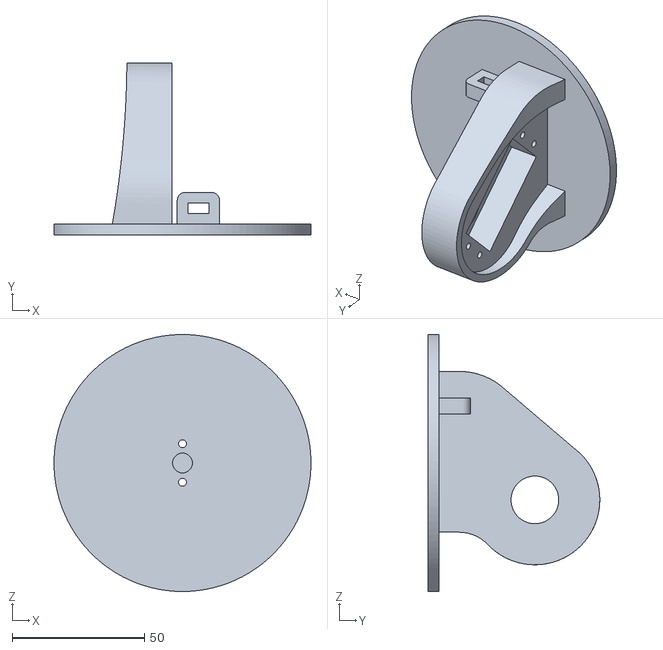
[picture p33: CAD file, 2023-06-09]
Resources/Arduino Robot Arm STL Files/STL/Waist.STL
97.0 x 64.8 x 97.0

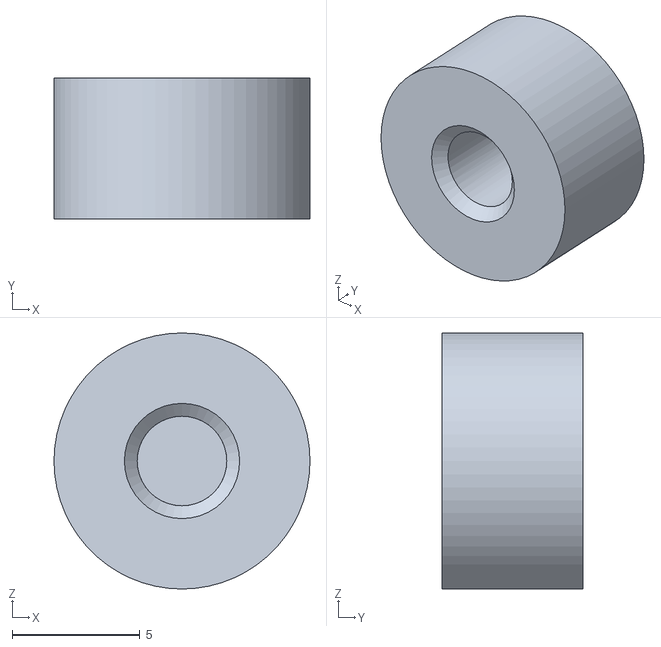
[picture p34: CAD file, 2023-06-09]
Resources/Robot Arm MK2 Plus/finalholder.STL
10.0 x 5.50 x 10.0

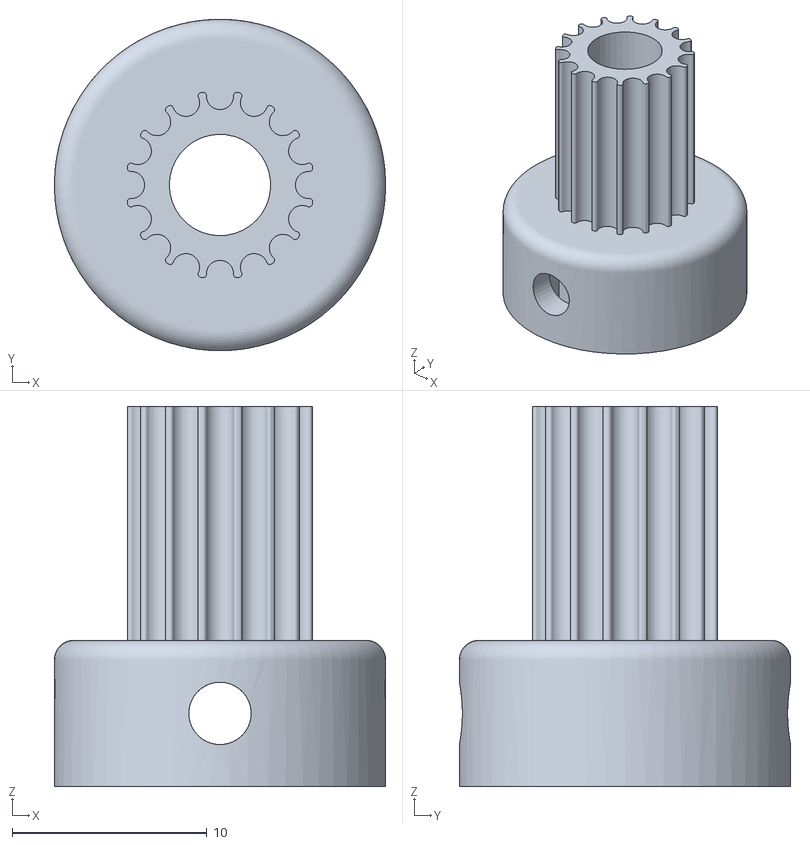
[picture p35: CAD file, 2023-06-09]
Resources/1204552_3d_print_desktop_robot_arm_DARM_/files/GT2_16tooth.STL
17.0 x 17.0 x 19.5

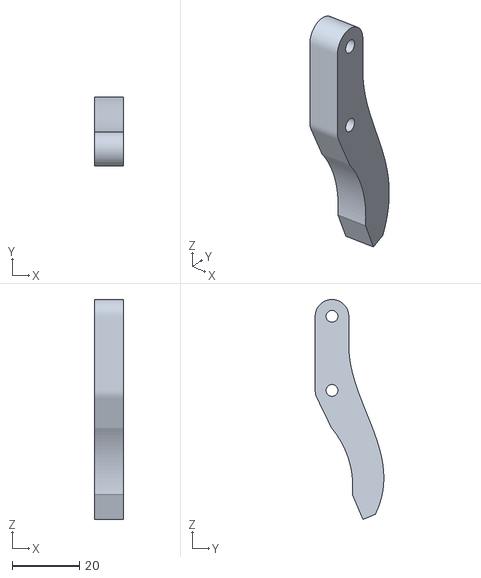
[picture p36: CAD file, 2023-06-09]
Resources/Arduino Robot Arm STL Files/STL/Gripper 1.STL
8.50 x 20.4 x 65.3

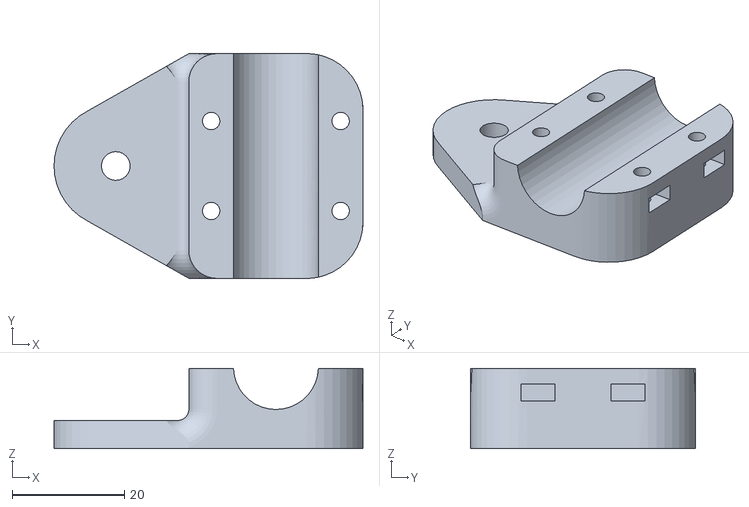
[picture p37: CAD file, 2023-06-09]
Resources/1204552_3d_print_desktop_robot_arm_DARM_/files/15mm_bracket_1.STL
55.0 x 40.0 x 14.3

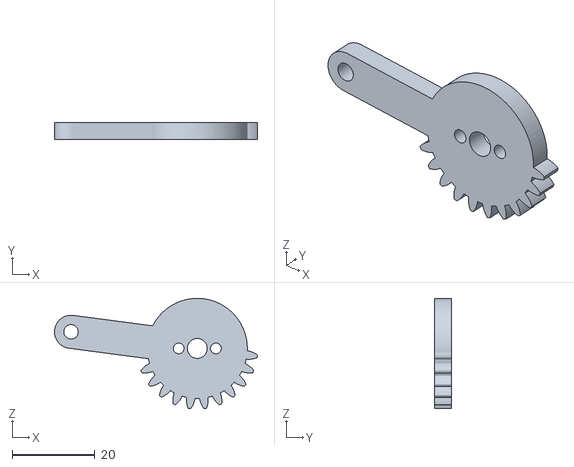
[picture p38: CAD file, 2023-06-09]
Resources/Arduino Robot Arm STL Files/STL/gear2.STL
49.0 x 4.00 x 26.6

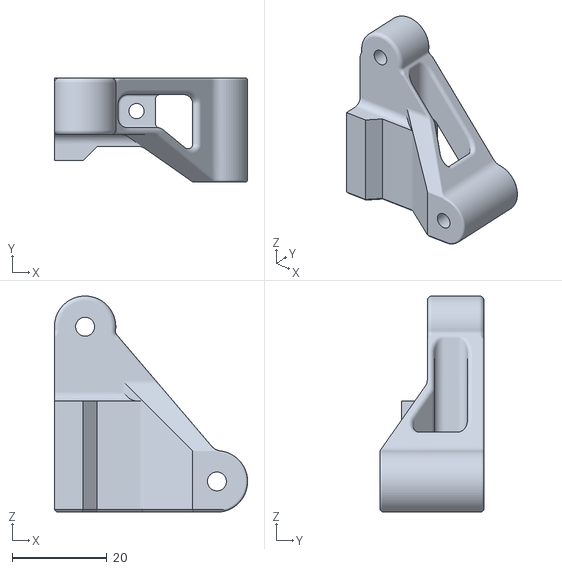
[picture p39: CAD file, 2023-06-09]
Resources/Robot Arm MK2 Plus/EBAmk2_009_trialinkfront.STL
40.9 x 22.0 x 45.7

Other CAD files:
Resources/1204552_3d_print_desktop_robot_arm_DARM_/files/mainArmEndstop.STL
Resources/Arduino Robot Arm STL Files/STL/gear1.STL
Resources/Robot Arm MK2 Plus/EBAmk2_016_claw_gear_drive.STL
Resources/1204552_3d_print_desktop_robot_arm_DARM_/files/end1.STL
Resources/1204552_3d_print_desktop_robot_arm_DARM_/files/1065_connect.STL
Resources/1204552_3d_print_desktop_robot_arm_DARM_/files/15mm_bracket.STL
Resources/1204552_3d_print_desktop_robot_arm_DARM_/files/15mm_bracket_2.STL
Resources/1204552_3d_print_desktop_robot_arm_DARM_/files/675_cennect.STL
Resources/1204552_3d_print_desktop_robot_arm_DARM_/files/690_connect.STL
Resources/1204552_3d_print_desktop_robot_arm_DARM_/files/8MMLock.STL
Resources/1204552_3d_print_desktop_robot_arm_DARM_/files/Gears_bottom.STL
Resources/1204552_3d_print_desktop_robot_arm_DARM_/files/Pen_clip.STL
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

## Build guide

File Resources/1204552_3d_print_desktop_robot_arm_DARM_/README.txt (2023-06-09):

This thing was created by Thingiverse user seagull008, and is licensed under cc.

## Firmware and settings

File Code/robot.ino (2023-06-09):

String command;

const int StepX = 2;
const int DirX = 5;
const int StepY = 3;
const int DirY = 6;
const int StepZ = 4;
const int DirZ = 7;

void setup() {
  Serial.begin(9600);

  pinMode(StepX,OUTPUT);
  pinMode(DirX,OUTPUT);
  pinMode(StepY,OUTPUT);
  pinMode(DirY,OUTPUT);
  pinMode(StepZ,OUTPUT);
  pinMode( DirZ,OUTPUT);

  delay(2000);

  Serial.println("Ready");
}

void loop() {
    if (Serial.available() > 0) {
        command = Serial.readStringUntil('\n');
        command.trim();
        if (command == "Start") {
            
        }
}
